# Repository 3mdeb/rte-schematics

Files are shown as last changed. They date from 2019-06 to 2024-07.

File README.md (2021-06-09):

Schematics for RTE system
=========================

This repository contains source files for Remote Testing Environment schematics.

If you want to read more about this project, here are some useful links:

* Firmware/software:
  - [meta-rte](https://github.com/3mdeb/meta-rte) - custom firmware for OrangePi
  Zero ([MIT license](https://github.com/3mdeb/meta-rte/blob/master/COPYING.MIT))
  - [RteCtrl](https://github.com/3mdeb/RteCtrl) - binary for power management on
  board ([MIT license](https://github.com/3mdeb/RteCtrl/blob/master/LICENSE))
* Datasheets (under CC BY-SA 4.0 International License):
  - [RTE v1.0.0 datasheet](https://cloud.3mdeb.com/index.php/s/NQCAHopjSpMGT9z)
  - [RTE v1.1.0 datasheet](https://docs.dasharo.com/transparent-validation/rte/v1.1.0/specification/)

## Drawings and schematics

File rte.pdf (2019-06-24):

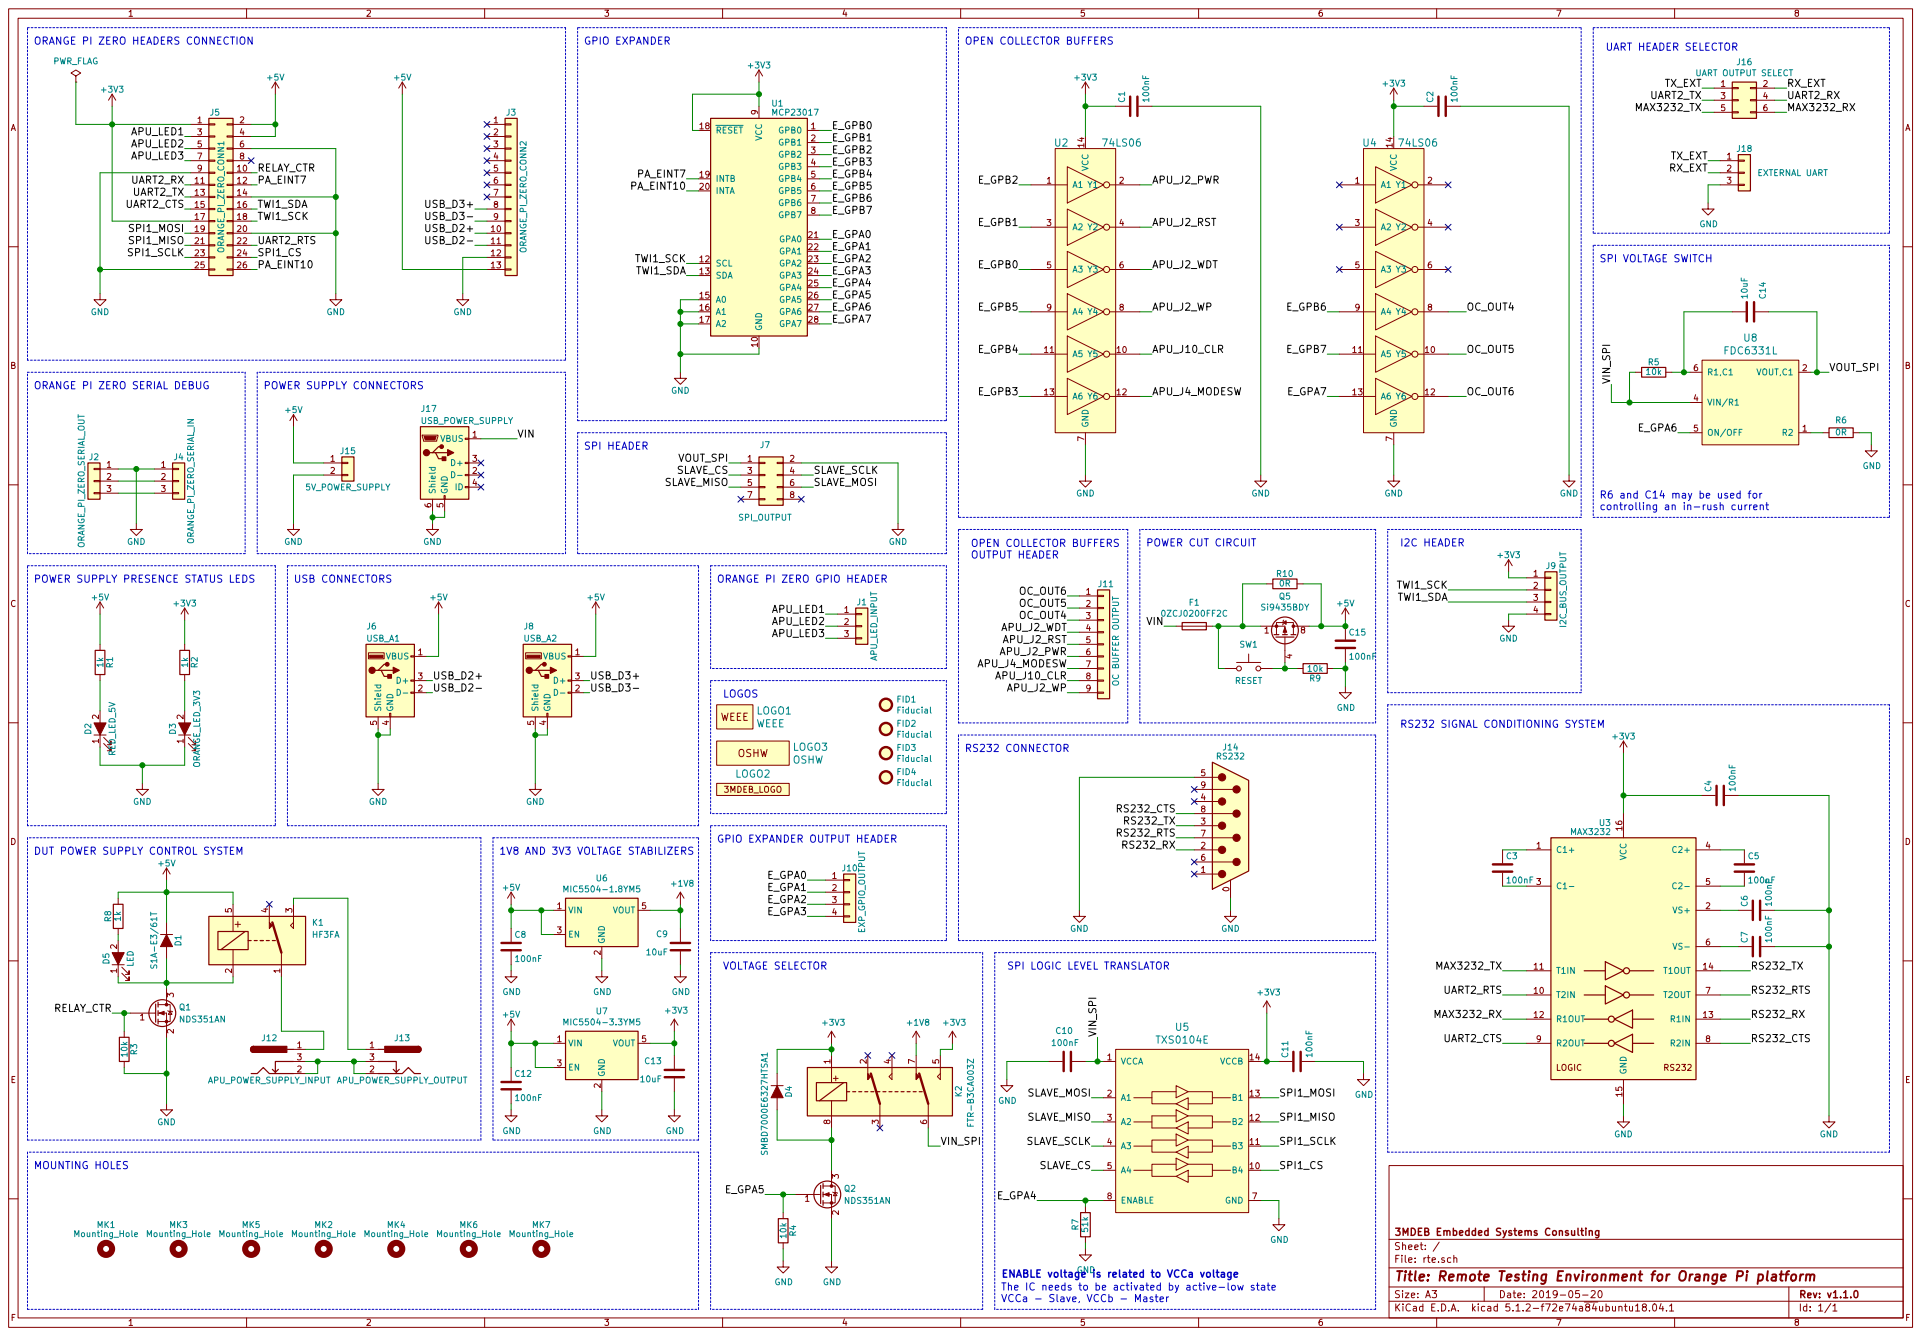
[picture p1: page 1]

ORANGE PI ZERO HEADERS CONNECTION

R6 and C14 may be used for

POWER SUPPLY PRESENCE STATUS LEDS

ORANGE PI ZERO GPIO HEADER

DUT POWER SUPPLY CONTROL SYSTEM

GPIO EXPANDER OUTPUT HEADER

SPI LOGIC LEVEL TRANSLATOR

File: rte.sch Sheet: / 3MDEB Embedded Systems Consulting

Id: 1/1 Title: Remote Testing Environment for Orange Pi platform

The IC needs to be activated by active-low state
VCCa - Slave, VCCb - Master

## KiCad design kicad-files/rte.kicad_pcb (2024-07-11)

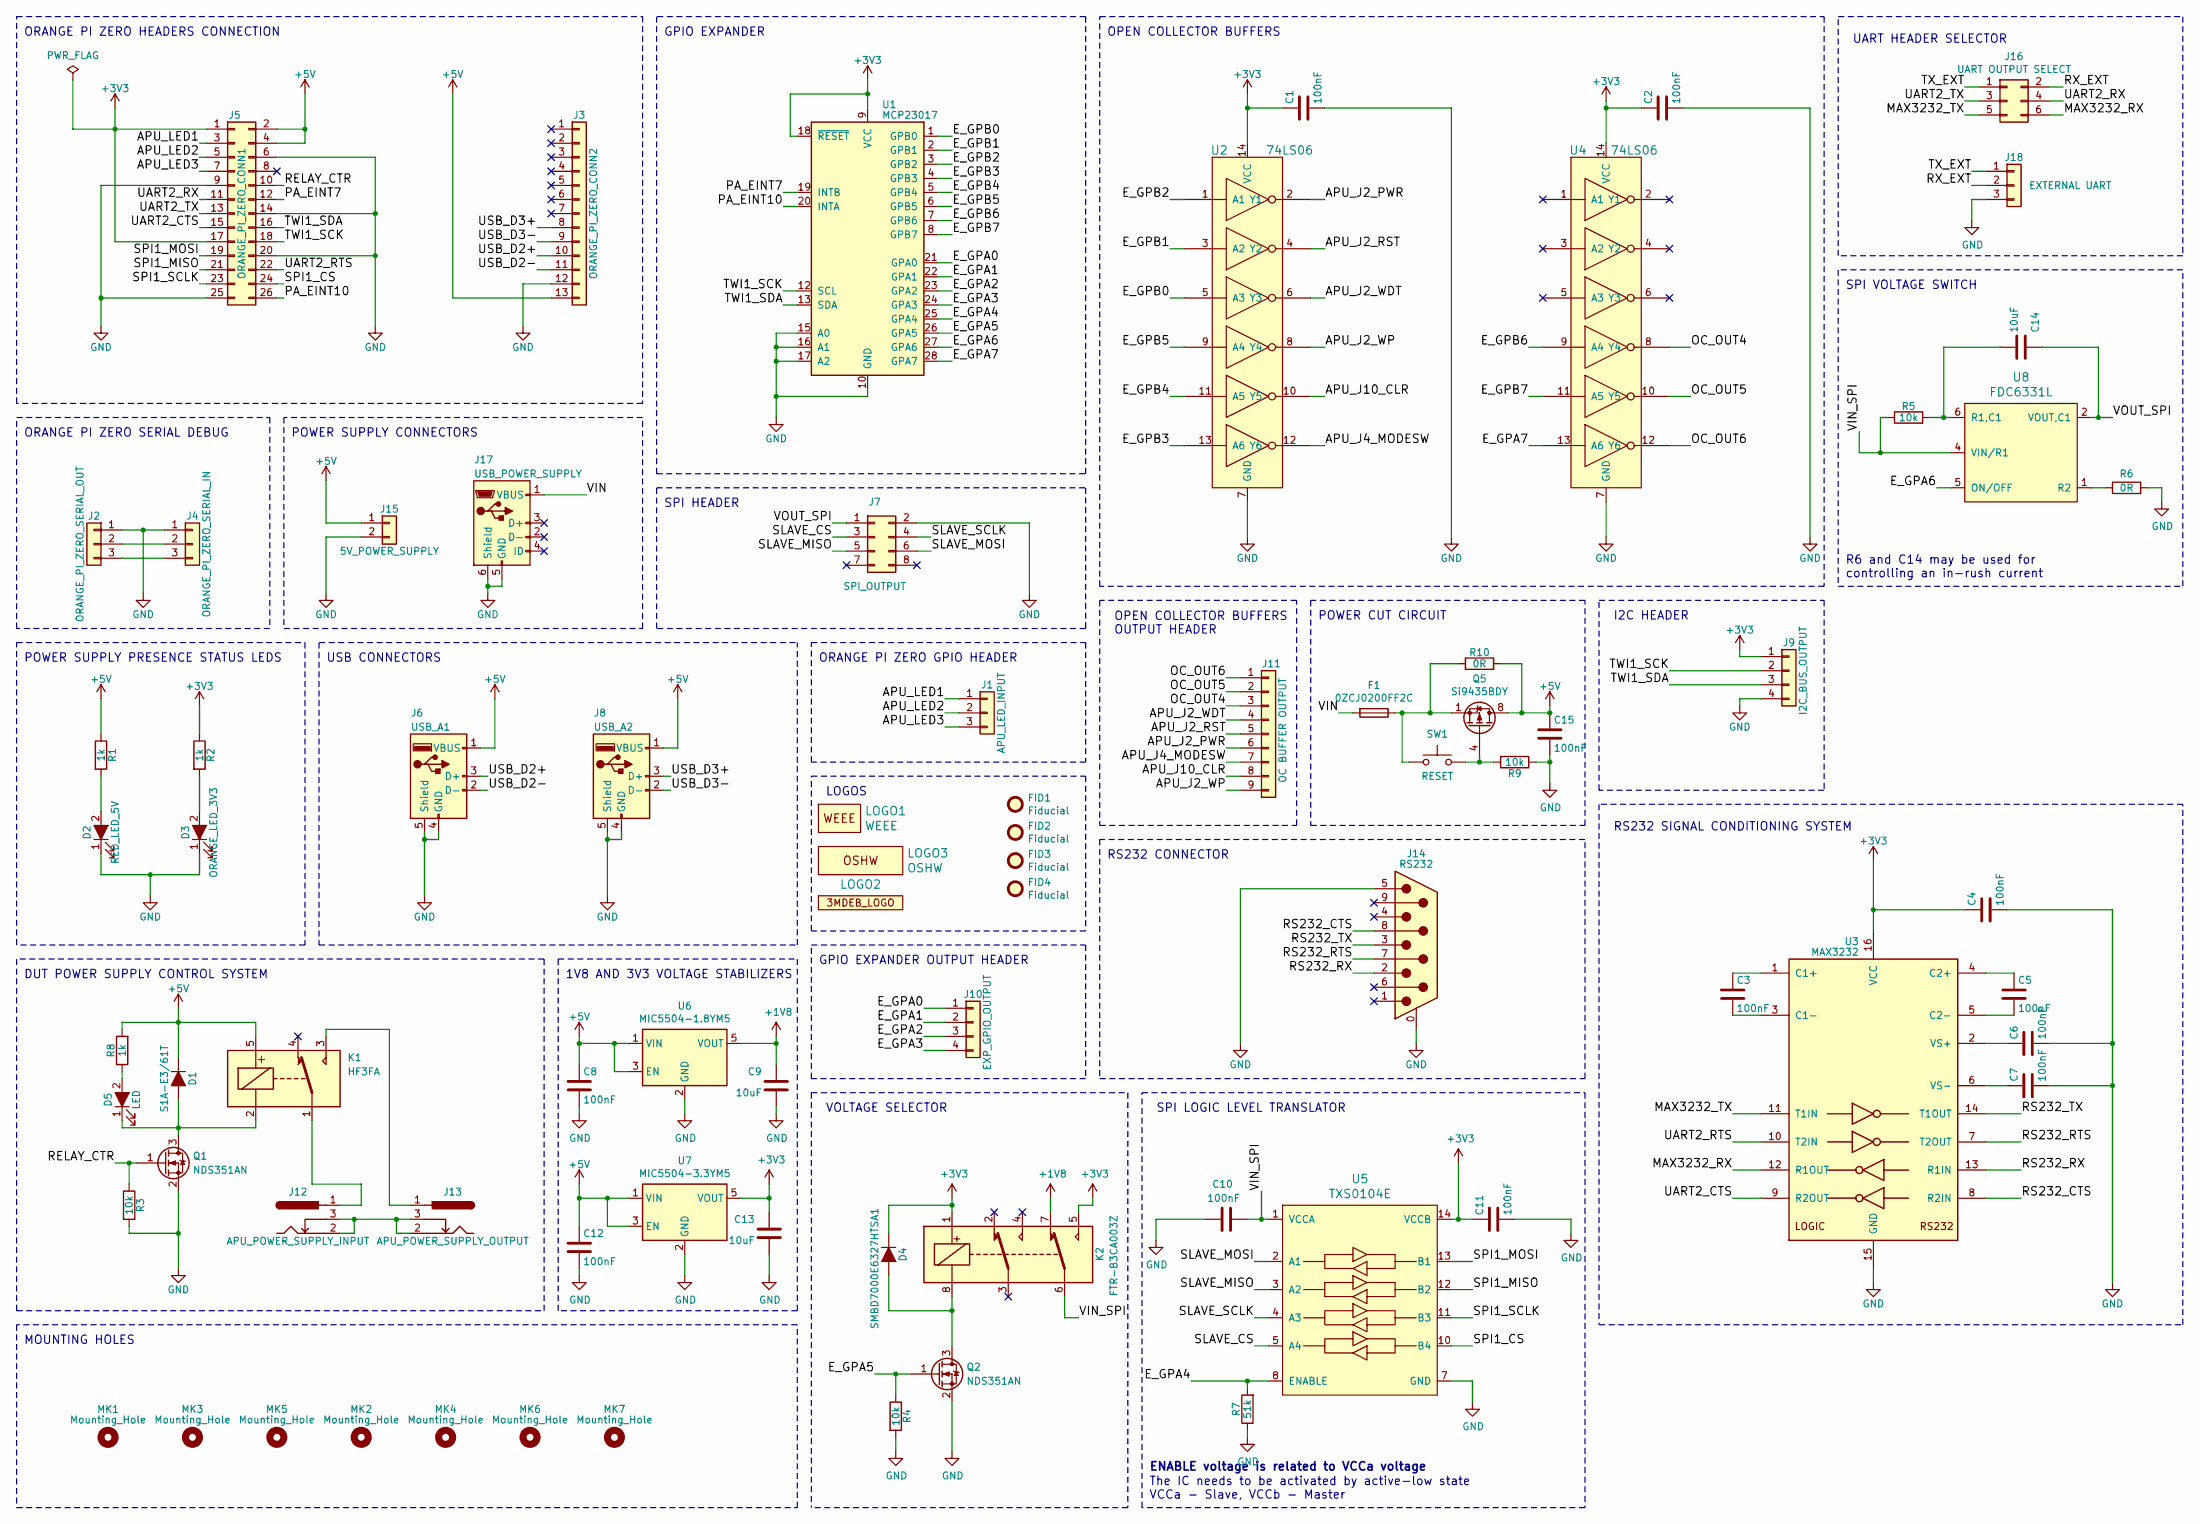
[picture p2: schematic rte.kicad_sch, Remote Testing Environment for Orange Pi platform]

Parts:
C1, C2, C3, C4, C5, C6, C7, C8, C10, C11, C12, C15: 100nF; C_0805_2012Metric; Voltage 50V
C9, C13, C14: 10uF; C_0805_2012Metric; Voltage 10V
D1: S1A-E3/61T; D_SMA; Voltage 50V
D2: RED_LED_5V; LED_1206_3216Metric
D3: ORANGE_LED_3V3; LED_1206_3216Metric
D4: SMBD7000E6327HTSA1; D_SOT-23_ANK
D5: LED; LED_1206_3216Metric
F1: 0ZCJ0200FF2C; Fuse_1206_3216Metric
FID1, FID2, FID3, FID4: Fiducial; Fiducial_0.75mm_Mask2.25mm
J1: APU_LED_INPUT; PinHeader_1x03_P2.54mm_Vertical
J2: ORANGE_PI_ZERO_SERIAL_OUT; PinHeader_1x03_P2.54mm_Vertical
J3: ORANGE_PI_ZERO_CONN2; PinSocket_1x13_P2.54mm_Vertical
J4: ORANGE_PI_ZERO_SERIAL_IN; PinSocket_1x03_P2.54mm_Vertical
J5: ORANGE_PI_ZERO_CONN1; PinSocket_2x13_P2.54mm_Vertical
J6: USB_A1; USB_A_Vertical
J7: SPI_OUTPUT; PinHeader_2x04_P2.54mm_Vertical
J8: USB_A2; USB_A_Vertical
J9: I2C_BUS_OUTPUT; PinHeader_1x04_P2.54mm_Vertical
J10: EXP_GPIO_OUTPUT; PinHeader_1x04_P2.54mm_Vertical
J11: OC BUFFER OUTPUT; PinHeader_1x09_P2.54mm_Vertical
J12: APU_POWER_SUPPLY_INPUT; BarrelJack_Horizontal
J13: APU_POWER_SUPPLY_OUTPUT; BarrelJack_Horizontal
J14: RS232; DB9MD
J15: 5V_POWER_SUPPLY; PinHeader_1x02_P2.54mm_Vertical
J16: UART OUTPUT SELECT; PinHeader_2x03_P2.54mm_Vertical
J17: USB_POWER_SUPPLY; USB_Micro-B
J18: EXTERNAL UART; PinHeader_1x03_P2.54mm_Vertical
K1: HF3FA; Relay_SPDT_SANYOU_SRD_Series_Form_C; Voltage 5V
K2: FTR-B3CA003Z; Relay_DPDT_AXICOM_IMSeries_Pitch5.08mm
LOGO1: WEEE; WEEE-Logo_4.2x6mm_SilkScreen
LOGO2: 3MDEB_LOGO; 3mdeb_logo
LOGO3: OSHW; OSHW-Logo2_7.3x6mm_SilkScreen
MK1, MK2, MK3, MK4, MK5, MK6, MK7: Mounting_Hole; MountingHole_2.7mm_Pad
Q1, Q2: NDS351AN; TSOT-23; Voltage 30V
Q5: Si9435BDY; SO-8_5.3x6.2mm_P1.27mm
R1, R2: 1k; R_1206_3216Metric
R3, R4, R5, R9: 10k; R_0805_2012Metric
R6: 0R; R_0805_2012Metric
R7: 51k; R_0805_2012Metric; Voltage 50V
R8: 1k; R_0805_2012Metric
R10: 0R; R_1206_3216Metric
SW1: RESET; SW_SPST_PTS645
U1: MCP23017; SOIC-28W_7.5x17.9mm_P1.27mm
U2, U4: 74LS06; SOIC-14_3.9x8.7mm_P1.27mm
U3: MAX3232; SOIC-16_3.9x9.9mm_P1.27mm
U5: TXS0104E; TSSOP-14_4.4x5mm_P0.65mm
U6: MIC5504-1.8YM5; SOT-23-5
U7: MIC5504-3.3YM5; SOT-23-5
U8: FDC6331L; SuperSOT-6

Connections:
+1V8: C9.2, K2.7, U6.5 (VOUT)
+3V3: C1.1, C2.1, C4.1, C11.1, C13.2, D4.1 (K), J5.1, J5.17, J9.1, K2.1, K2.5, R2.1, U1.9 (VCC), U1.18 (~RESET), U2.14 (VCC), U3.16 (VCC), U4.14 (VCC), U5.14 (VCCB), U7.5 (VOUT)
+5V: C8.1, C12.1, C15.1, D1.1 (K), J3.13, J5.2, J5.4, J6.1 (VBUS), J8.1 (VBUS), J15.1, K1.5, Q5.5 (D), Q5.6 (D), Q5.7 (D), Q5.8 (D), R1.1, R8.2, R10.2, U6.1 (VIN), U6.3 (EN), U7.1 (VIN), U7.3 (EN)
/APU_J2_PWR: J11.6, U2.2 (Y1)
/APU_J2_RST: J11.5, U2.4 (Y2)
/APU_J2_WDT: J11.4, U2.6 (Y3)
/APU_J2_WP: J11.9, U2.8 (Y4)
/APU_J4_MODESW: J11.7, U2.12 (Y6)
/APU_J10_CLR: J11.8, U2.10 (Y5)
/APU_LED1: J1.1, J5.3
/APU_LED2: J1.2, J5.5
/APU_LED3: J1.3, J5.7
/E_GPA0: J10.1, U1.21 (GPA0)
/E_GPA1: J10.2, U1.22 (GPA1)
/E_GPA2: J10.3, U1.23 (GPA2)
/E_GPA3: J10.4, U1.24 (GPA3)
/E_GPA4: R7.2, U1.25 (GPA4), U5.8 (ENABLE)
/E_GPA5: Q2.1 (G), R4.1, U1.26 (GPA5)
/E_GPA6: U1.27 (GPA6), U8.5 (ON/OFF)
/E_GPA7: U1.28 (GPA7), U4.13 (A6)
/E_GPB0: U1.1 (GPB0), U2.5 (A3)
/E_GPB1: U1.2 (GPB1), U2.3 (A2)
/E_GPB2: U1.3 (GPB2), U2.1 (A1)
/E_GPB3: U1.4 (GPB3), U2.13 (A6)
/E_GPB4: U1.5 (GPB4), U2.11 (A5)
/E_GPB5: U1.6 (GPB5), U2.9 (A4)
/E_GPB6: U1.7 (GPB6), U4.9 (A4)
/E_GPB7: U1.8 (GPB7), U4.11 (A5)
/MAX3232_RX: J16.6, U3.12 (R1OUT)
/MAX3232_TX: J16.5, U3.11 (T1IN)
/OC_OUT4: J11.3, U4.8 (Y4)
/OC_OUT5: J11.2, U4.10 (Y5)
/OC_OUT6: J11.1, U4.12 (Y6)
/PA_EINT7: J5.12, U1.19 (INTB)
/PA_EINT10: J5.26, U1.20 (INTA)
/RELAY_CTR: J5.10, Q1.1 (G), R3.1
/RS232_CTS: J14.8, U3.8 (R2IN)
/RS232_RTS: J14.7, U3.7 (T2OUT)
/RS232_RX: J14.2, U3.13 (R1IN)
/RS232_TX: J14.3, U3.14 (T1OUT)
/RX_EXT: J16.2, J18.2
/SLAVE_CS: J7.3, U5.5 (A4)
/SLAVE_MISO: J7.5, U5.3 (A2)
/SLAVE_MOSI: J7.6, U5.2 (A1)
/SLAVE_SCLK: J7.4, U5.4 (A3)
/SPI1_CS: J5.24, U5.10 (B4)
/SPI1_MISO: J5.21, U5.12 (B2)
/SPI1_MOSI: J5.19, U5.13 (B1)
/SPI1_SCLK: J5.23, U5.11 (B3)
/TWI1_SCK: J5.18, J9.2, U1.12 (SCL)
/TWI1_SDA: J5.16, J9.3, U1.13 (SDA)
/TX_EXT: J16.1, J18.1
/UART2_CTS: J5.15, U3.9 (R2OUT)
/UART2_RTS: J5.22, U3.10 (T2IN)
/UART2_RX: J5.11, J16.4
/UART2_TX: J5.13, J16.3
/USB_D2+: J3.10, J6.3 (D+)
/USB_D2-: J3.11, J6.2 (D-)
/USB_D3+: J3.8, J8.3 (D+)
/USB_D3-: J3.9, J8.2 (D-)
/VIN: F1.2, J17.1 (VBUS)
/VIN_SPI: C10.2, K2.6, R5.1, U5.1 (VCCA), U8.4 (VIN/R1)
/VOUT_SPI: C14.2, J7.1, U8.2 (VOUT,C1), U8.3 (VOUT,C1)
GND: C1.2, C2.2, C4.2, C6.2, C7.2, C8.2, C9.1, C10.1, C11.2, C12.2, C13.1, C15.2, D2.1 (K), D3.1 (K), J2.1, J3.12, J4.1, J5.6, J5.9, J5.14, J5.20, J5.25, J6.4 (GND), J6.5 (Shield), J7.2, J8.4 (GND), J8.5 (Shield), J9.4, J14.0 (PAD), J14.5, J15.2, J17.5 (GND), J17.6 (Shield), J18.3, Q1.2 (S), Q2.2 (S), R3.2, R4.2, R6.2, R7.1, R9.1, U1.10 (GND), U1.15 (A0), U1.16 (A1), U1.17 (A2), U2.7 (GND), U3.15 (GND), U4.7 (GND), U5.7 (GND), U6.2 (GND), U7.2 (GND)
unnamed: C3.1, U3.1 (C1+)
unnamed: C3.2, U3.3 (C1-)
unnamed: C5.1, U3.4 (C2+)
unnamed: C5.2, U3.5 (C2-)
unnamed: C6.1, U3.2 (VS+)
unnamed: C7.1, U3.6 (VS-)
unnamed: C14.1, R5.2, U8.6 (R1,C1)
unnamed: D1.2 (A), D5.1 (K), K1.2, Q1.3 (D)
unnamed: D2.2 (A), R1.2
unnamed: D3.2 (A), R2.2
unnamed: D4.2 (A), K2.8, Q2.3 (D)
unnamed: D5.2 (A), R8.1
unnamed: F1.1, Q5.1 (S), Q5.2 (S), Q5.3 (S), R10.1, SW1.1
unnamed: J2.2, J4.2
unnamed: J2.3, J4.3
unnamed: J12.1, K1.1
unnamed: J12.2, J12.3, J13.2, J13.3
unnamed: J13.1, K1.3
unnamed: Q5.4 (G), R9.2, SW1.2
unnamed: R6.1, U8.1 (R2)

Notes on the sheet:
ORANGE PI ZERO HEADERS CONNECTION
UART HEADER SELECTOR
SPI HEADER
ORANGE PI ZERO GPIO HEADER
USB CONNECTORS
I2C HEADER
ENABLE voltage is related to VCCa voltage
LOGOS
VOLTAGE SELECTOR
1V8 AND 3V3 VOLTAGE STABILIZERS
POWER SUPPLY PRESENCE STATUS LEDS
RS232 SIGNAL CONDITIONING SYSTEM
GPIO EXPANDER
OPEN COLLECTOR BUFFERS OUTPUT HEADER
SPI VOLTAGE SWITCH
SPI LOGIC LEVEL TRANSLATOR
POWER CUT CIRCUIT
RS232 CONNECTOR
ORANGE PI ZERO SERIAL DEBUG
POWER SUPPLY CONNECTORS
MOUNTING HOLES
DUT POWER SUPPLY CONTROL SYSTEM
GPIO EXPANDER OUTPUT HEADER
OPEN COLLECTOR BUFFERS
The IC needs to be activated by active-low state VCCa - Slave, VCCb - Master
R6 and C14 may be used for controlling an in-rush current

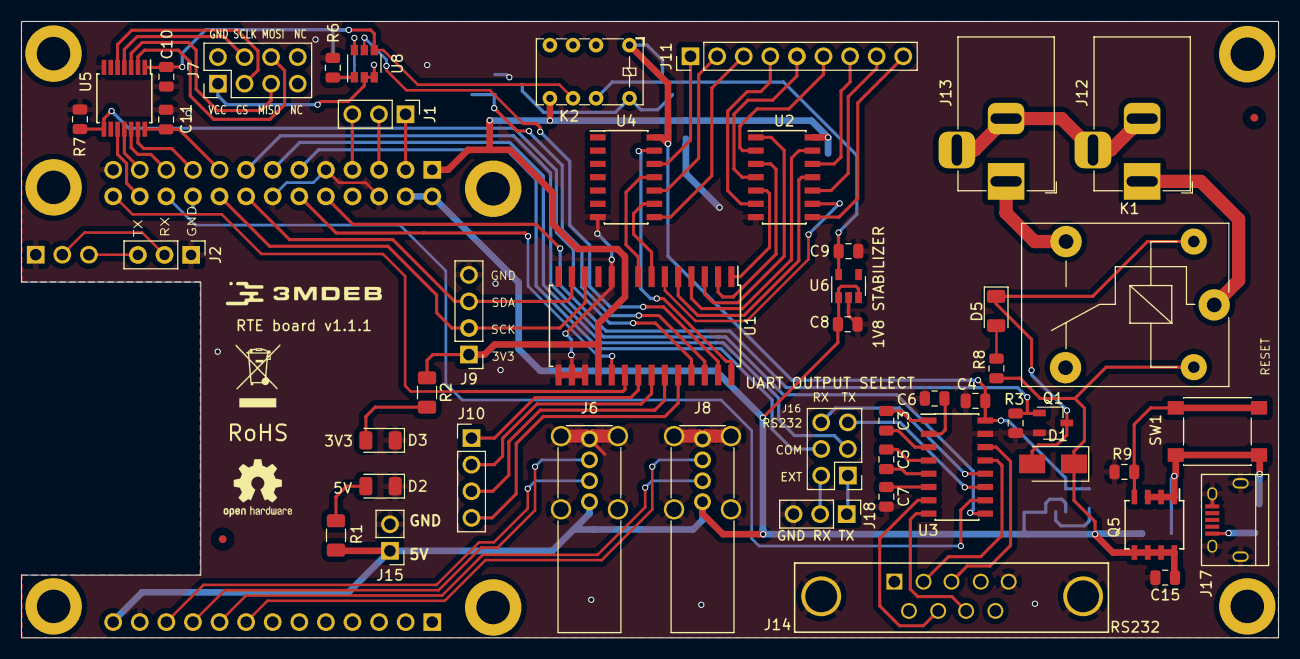
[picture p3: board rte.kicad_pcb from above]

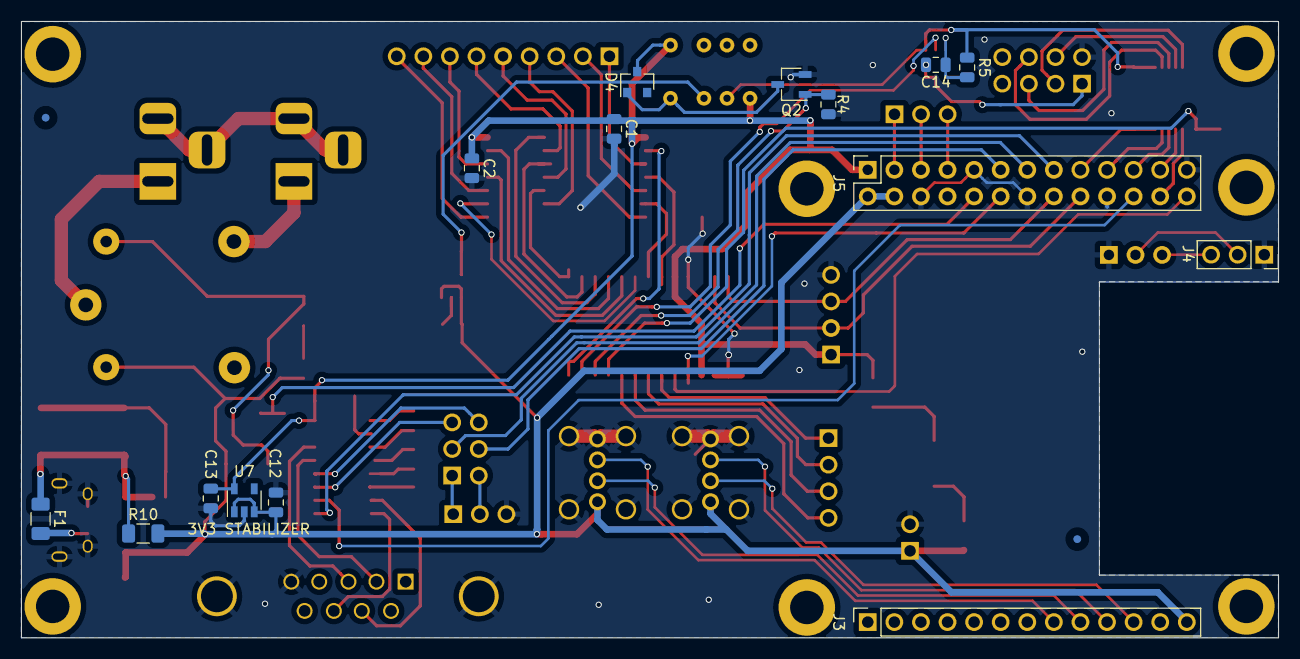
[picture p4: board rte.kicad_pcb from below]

Board: 2 copper layers, 120.1 x 58.9 mm, 77 parts (17 on the bottom side), 84 nets.

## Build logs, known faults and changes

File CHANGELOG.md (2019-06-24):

RTE Board changelog
===================

v. 1.1.0
--------

Added:

* 3.3V voltage stabilizer
* 1.8V voltage stabilizer
* A SPI logic level converter
* A Voltage selector based on a relay
* An Open Hardware logo
* An UART header selector
* A `MAX3232` enable jumper
* A relay state diode
* A circuit for cut-off the current flow
* A `.gitignore` file

Modified:

* OC header (from now on, there are only 9 open-collector pins free to use)
* Resistors and capacitors footprints
=======
Removed:
* ARK joint for relay module
* Header for relay module control

v. 1.0.0
--------

Added:

* RoHS logo
* Crossed Wheelie Bin logo

Modified:

* footprints of the pin headers

v. 0.5.3
--------

Modified:
* enlarged added holes

v. 0.5.2
--------

Modified:
* I2C GPIO expander outputs connections (now 4 of them are connected to the dedicated header)
* version number on board

Removed:
* SPI header for APU recovery with output pin role information labels
* 7 and 8 pin of SPI header with GPIO expander connection

v. 0.5.1
--------

Added:
* microUSB connector for power supply
* 5 V power supply pins
* SPI connector for APU SPI recovery
* fiducials on bottom layer
* pins information labels

Modified:
* relay control system elements placement
* SPI connector for APU paths placement
* project text descriptions

Removed:
* 2 pin GPIO expander connector

v. 0.5
------

Added:
* 5 V power supply signal diode (red) + limiting current resistor
* 3.3 V power supply signal diode (orange) + limiting current resistor

Modified:
* relay NO/NC connection switched to previous configuration
* switched `SPI1_MISO`with `SPI1_MOSI` output
* mirrored `RS232` socket pads

Removed:
* I2C pull-up resistors

v. 0.3.6
--------

Modified:
* relay NO/NC connection switched

v. 0.3.5
--------

Modified:
* enlarge the hole diameter by 0.1 mm

v. 0.3.4
--------

Added:
* 3mdeb logo and board name on PCB

Modified:
* elements marks placing

v. 0.3.3
--------

Added:
* SPI output IO pins connection with GPIO
* PCB mechanical schematic
* I2C INT pins connection
* mounting holes
* fiducials

Modified:
* mosfet transistor pinout numeration
* USB footprint from horizontal to vertical
* I2C GPIO expander with OC buffers connection

v. 0.3.2
--------

Added:
* mounting holes

Modified:
* relay pinout

Removed:
* I2C to GND connection

v. 0.3.1
--------

Modified:
* power supply from 5V to 3V3 for I2C bus `MCP23017`, and `MAX3232`

Removed:
* capacitors connected to I2C bus

v. 0.3
------

Added:
* I2C bus with output header
* `MCP23017` I2C GPIO expander
* second `SN74LS06` OC buffer
* relay with required neighboring items
* `MAX3232` RS232 electrical level changer
* RS232 socket
* GPIO output header for pins unused to OC buffer control

Modified:
* Some of input pins connetion
* footprints of the pin headers

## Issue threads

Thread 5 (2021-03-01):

document OC_OUT1-3 / GPIO404-406

orangecms, 2021-03-01:
The datasheet at https://cloud.3mdeb.com/index.php/s/HArgg8jrDmASWGp refers to the following (section "SPI header"):

| OC pin | GPIO pin | function |
| - | - | - |
| OC_OUT1 | GPIO406 | enable SPI VCC |
| OC_OUT2 | GPIO405 | set SPI VCC to 3.3V |
| OC_OUT3 | GPIO404 | enable SPI lines |

The schematics show the J11 header, which lists `OC_OUT4`, `OC_OUT5`, `OC_OUT6`. It seems like something is mixed up here.

miczyg1, 2021-03-01:
These signals are controlled with E_GPA{4,5,6} wich correspond to GPIO{404,405,406} seen in the Linux. The only error I see here is the first column which incorrectly states these are OC pins (which was probably true in older RTE revisions), but they are not, they are simply GPIOs from the I/O expander. @pkonkol could you please change the datasheet first column to something like this?

| Signal |
|----------|
| E_GPA6 |
| E_GPA5 |
| E_GPA4 |

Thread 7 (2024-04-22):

Integrate PiKVM-like functionality (video capture, USB gadget)

macpijan, 2024-04-22:
Many of the RTE and [PiKVM](https://pikvm.org/) features are common.

The RTE does some more (OC GPIOs, SPI flashing, relay), and PiKVM does some more (mainly USB gadget and HDMI capture).

By integrating the most important features of PiKVM into RTE, we could simplify most setups by having a single device.

USB gadget for HID/MSC emulation should be feasible, possibly on the existing board even (Orange Pi Zero0).

Video capture would need additional hw interace, however. In case of RPI, CSI camera input is used along with the HDMI - CSI bridge. Another requirement would be a hw acceleration of vide encoding - in case of PiKVM [ustreamer is used](https://github.com/pikvm/ustreamer) which supports RPi video encoder.

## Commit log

2018-04-02 RTE schematic and PCB uploaded
    [rte.kicad_pcb, rte.sch]
2019-04-03 Updated schematics to v1.0.0
    [rte.kicad_pcb, rte.sch]
2019-06-24 Updated schematic v1.1.0
2019-06-24 added pdf schematic, removed backup files
2024-07-11 Update Q5 footprint to match the Si9435BDY recommended footprint
    [rte.kicad_pcb]
2024-07-11 Refactor USB data lines to be more equal in length
    [rte.kicad_pcb]
2024-07-11 kicad-files/rte.kicad_pcb: Change board version to v1.1.1
    [rte.kicad_pcb]
2024-07-11 kicad-files/rte.kicad_pro: Add new format of project file
2024-07-11 kicad-files/rte.kicad_sch: Add new format of schematics file
    [rte.kicad_sch]
